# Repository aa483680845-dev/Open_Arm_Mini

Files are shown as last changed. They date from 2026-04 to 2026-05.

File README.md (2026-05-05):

# Open Arm Mini

基于 ROS2 的开源六自由度机械臂，通过 FDCAN 总线驱动达秒（Damiao）系列电机，采用 MIT 阻抗控制模式，支持真实硬件控制与 Mujoco 仿真，具备手柄末端控制和重力补偿功能。

另一个开源项目：moveit2轨迹规划:https://github.com/aa483680845-dev/Arm_Moveit2.git

运行环境：Ubuntu 24.04 LTS + ROS2 Jazzy

## 演示

**手柄控制**

https://github.com/user-attachments/assets/3d2e06fe-9ed9-414d-ab63-fa3fa3a4508c

**重力补偿**

https://github.com/user-attachments/assets/b24e1ee6-b301-45b6-a565-f904d05fffcf

## 目录结构

```
Open_Arm_Mini/
├── image/                  # 演示视频
├── SW_model/               # SolidWorks 机械臂三维模型
│   └── First_edition/
│       ├── SLDPRT/         # SolidWorks 原始零件文件
│       └── STEP/           # 通用 STEP 格式，可导入其他 CAD 软件
└── ros2_package/           # ROS2 控制软件包
    ├── robot_description/  # URDF/xacro 描述文件及 STL 网格模型
    ├── robot_dm_driver/    # 达秒电机底层驱动（FDCAN/MIT 协议）
    ├── my_robot_hardware/  # ROS2 硬件接口层
    ├── robot_controllers/  # 电机控制器（手柄控制 / 重力补偿）
    ├── robot_pinocchio/    # Pinocchio 逆运动学节点
    ├── robot_bringup/      # Launch 启动文件及控制器配置
    └── README.md           # 软件包详细文档
```

## 软件包文档

ROS2 软件包的详细说明（环境配置、编译运行、架构设计、各包接口）请参阅

👉 [ros2_package/README.md](ros2_package/README.md)

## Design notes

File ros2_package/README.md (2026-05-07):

## 项目概述

本项目是基于 ROS2 的**六自由度机械臂控制系统**，通过 FDCAN 总线驱动达秒（Damiao）系列电机，采用 MIT 阻抗控制模式，支持真实硬件控制、Mujoco 仿真，控制方面可以采用手柄控制末端关节，拥有重力补偿功能。

## 环境配置

运行在 Ubuntu 24.04 LTS 系统上，ROS2 Jazzy 版本。

### 依赖安装

```bash
sudo apt install ros-jazzy-ros2-control ros-jazzy-ros2-controllers
sudo apt install ros-jazzy-joy
sudo apt install ros-jazzy-pinocchio
sudo apt install libusb-1.0-0-dev
```

### 可视化工具（可选）

```bash
sudo apt install ros-jazzy-plotjuggler
```

## 编译与运行

```bash
cd ~/Project/ros2_package
colcon build --symlink-install
source install/setup.bash
```

### 控制方案切换

配置文件：`robot_description/urdf/robot_1.ros2_control.xacro` 的 `<plugin>` 部分：

| 插件 | 用途 |
|---|---|
| `mock_components/GenericSystem` | 模拟组件，用于代码调试（当前默认） |
| `mobile_base_hardware/MobileBaseHardwareInterface` | 真实硬件，需接 USB2CAN 连接电机 |
| `mujoco_ros2_control/MujocoSystemInterface` | Mujoco 仿真 |

### 启动命令

```bash
# 运行控制节点（真实/模拟硬件）
ros2 launch robot_bringup robot_controllers.launch.py

# 运行 Mujoco 仿真节点
ros2 launch robot_bringup robot_mujoco.launch.py

# 运行手柄 + Pinocchio 逆运动学控制
ros2 launch robot_bringup my_robot_pin.launch.py
```

## 软件包架构

```
手柄输入 → PinocchioInverseNode → arm_MIT_command_controller/commands
                                              ↓
                               MotorController（position_ff / gravity_comp）
                                              ↓
                               MobileBaseHardwareInterface（250 Hz 循环）
                                              ↓  
                               robot_dm_driver（CAN 协议，CANFD）
                                              ↓
                               达秒电机（MIT 阻抗：kp·Δq + kd·Δdq + τ_ff）
```

### 各软件包简要说明（多数软件包内部都写了README.md文档）

| 软件包 | 功能 |
|---|---|
| `robot_description` | 包含 URDF、xacro、xml机械臂描述文件，STL网格模型，主要需要修改的是robot_1.ros2_control.xacro，可以修改MIT增益参数、控制模式|
| `robot_dm_driver` | 包含[达秒官方的封装闭源库](https://gitee.com/kit-miao/dm-tools/tree/master/DM_DeviceSDK/C&C++) `libdm_device.so`，pub_user.h API 接口, src里面写的是对API的实现包含MIT控制模式的实现，接收电机反馈数据。|
| `my_robot_hardware` | 介于控制器和底层API之间，实现了 ROS2 硬件接口，起到的主要作用是设置电机ID、发送控制器的指令、接收电机反馈数据传送给控制器(如：关节广播控制器) |
| `robot_controllers` | 含有两种控制模式，一个是手柄控制，接收上层节点的关节速度指令，积分为位置，另一种是接收位置指令，通过pinocchio的函数实现重力补偿，此外控制器还包含了低通滤波。控制器控制模式可以通过配置文件修改：`robot_bringup/config/ros2_controllers.yaml` |
| `robot_pinocchio` | DLS 逆运动学节点，手柄轴输入 → 关节速度指令，250 Hz 定时发布 |
| `robot_bringup` | Launch 启动文件及控制器 YAML 配置文件，和一个rviz保存的配置文件 |

### 电机驱动（`robot_dm_driver`）
- 只要是达秒拥有MIT控制的电机应该是都可以用的，本项目仅使用了 DM_4340 和 DM_4310 系列
- 关于MIT控制详细内容请参考[达秒官方文档](https://gl1po2nscb.feishu.cn/wiki/Y3OEwMr4GivZU9kZqkjctmGinye)
- CANFD 双波特率：标称 1 Mbps，数据段 5 Mbps
- `libdm_device.so` 为[达秒官方的闭源二进制库](https://gitee.com/kit-miao/dm-tools/tree/master/DM_DeviceSDK/C&C++)，位于 `robot_dm_driver/lib/`，运行时必须存在
- 电机状态由互斥锁保护，读取时使用 `dm_motor_snapshot(idx, &q, &dq, &tau)` 保证线程安全

### 硬件接口（`my_robot_hardware`）
- 类名：`MobileBaseHardwareInterface`（命名有误导性，实为机械臂接口）
- 插件描述文件：`my_robot_hardware_interface.xml`
- **`on_init()`**：从 URDF `<param>` 读取每关节 kp/kd，创建 damiao handle，查找 USB2CAN 设备
- **`on_configure()`**：打开设备，打印固件版本和序列号
- **`on_activate()`**：初始化 CANFD 通道，注册 6 个电机（CAN ID 0x01–0x06），开启通道，使能控制，等待最多 500 ms 接收首次反馈
- **`read()`**：突变滤波（偏差 > 0.2 rad 则保持上帧值）+ 低通滤波（alpha=0.4）
- **`write()`**：调用 `dm_control_mit()` 透传 pos/vel/eff，含 NaN 保护（跳过异常帧）

### 电机控制器（`robot_controllers`）
- 命名空间：`robot_controller::MotorController`（注意：非 `robot_controllers`）
- 插件：`robot_controller::MotorController`
- **`position_ff` 模式**（默认）：读取速度指令（`data[i*3+1]`），低通滤波（alpha=0.4），积分出位置目标，dt 限幅 [0.5 ms, 10 ms]
- **`gravity_comp` 模式**：使用 Pinocchio `computeGeneralizedGravity()` 计算重力力矩，pos=当前位置，vel=0，eff=τ_gravity
- 订阅话题：`arm_MIT_command_controller/commands`（`Float64MultiArray`，18 元素，每关节 `[pos, vel, eff]`）

### Pinocchio 逆运动学（`robot_pinocchio`）
- 节点名：`pinocchio_inverse_node`
- 使用阻尼最小二乘法（DLS）雅可比伪逆，`IK_DT=0.04`，奇异点阈值 `IK_EPS=0.01`
- 定时器周期 4 ms（约 250 Hz）发布关节速度指令
- 手柄左摇杆（LEFTX/LEFTY）→ 末端笛卡尔速度 → DLS 映射为 6 个关节速度,本项目没有添加末端姿态控制，如果需要你可以尝试添加；
- 速度缩放因子 `factor=0.03`，奇异度指标 `ratio`（< 1 表示接近奇异）
- 订阅 `joint_states`关节状态，发布到 `arm_MIT_command_controller/commands`控制器
- URDF 路径通过 `ament_index_cpp::get_package_share_directory("robot_description")` 动态获取

### 控制器配置
- 更新频率：250 Hz（在 `robot_bringup/config/ros2_controllers.yaml` 中设置）
- 各关节 kp/kd 增益定义在 `robot_description/urdf/robot_1.ros2_control.xacro`
- **注意**：`ros2_controllers.yaml` 中 URDF 路径为绝对路径，工作空间移动后需同步修改

## 未来更新
-本项目代码还有许多问题，之后会积极改进。
-关于机械臂新的功能的更新，本人会更侧重于 moveit2 这个项目:https://github.com/aa483680845-dev/Arm_Moveit2.git

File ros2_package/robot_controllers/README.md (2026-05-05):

# robot_controllers

## 概述

本包实现了一个自定义 ROS2 控制器 `MotorController`，用于驱动六自由度机械臂的达秒（Damiao）系列电机，支持**位置前馈（position_ff）**和**重力补偿（gravity_comp）**两种控制模式。

##个人吐槽

写自定义控制器其实不是必要的，如果想要分别实现手柄控制和重力补偿，可以使用官方提供的forward_command_controller和force_torque_sensor_broadcaster控制器，使用launch选择性的加载控制器。
如果想要实现在重力补偿的基础上实现遥控制，可以将重力补偿部分写入hardware_interface。至于为什么自写控制器，主要是当时我刚开始学习ros2_control，觉得自己要实现的功能官方提供的控制器无法满足。
其次，自写控制器不用担心上点跳变到零点问题，还可以自己在控制器中加入一些滤波逻辑，集成度更高（doge），还有控制器的逻辑和硬件组件的逻辑差不多，所以并不难写。

## 控制模式

通过配置文件中的 `control_mode` 参数切换，配置文件路径：`robot_bringup/config/ros2_controllers.yaml`。

### `position_ff`（默认）

接收上游发布的关节**速度指令**，经低通滤波后积分为位置目标，同时将滤波后的速度作为前馈量发送给硬件。

```
速度指令 (vel_cmd)
    → 低通滤波（alpha = 0.4）
    → 积分（dt 限幅 [0.5ms, 10ms]）
    → 位置目标 (pos_cmd)
    → 硬件接口 [pos_cmd, vel_filtered, 0.0]
```

### `gravity_comp`

读取当前关节角，利用 Pinocchio `computeGeneralizedGravity()` 实时计算各关节重力补偿力矩，并将当前位置作为目标位置发送，使机械臂保持当前姿态的同时补偿重力。

```
当前关节角 q (来自 state_interfaces)
    → Pinocchio RNEA → τ_gravity = g(q)
    → 硬件接口 [q_now, 0.0, τ_gravity]
```

> 发送 `pos = q_now`，使 MIT 控制器中的 `kp*(q_now - q_actual) ≈ 0`，位置增益几乎不出力；
> 发送 `vel = 0`，MIT 控制器中的 `-kd * dq_actual` 提供速度阻尼。

---

## 接口说明

### 订阅话题

| 话题 | 消息类型 | 说明 |
|---|---|---|
| `arm_MIT_command_controller/commands` | `std_msgs/Float64MultiArray` | 上游指令，18 元素，每关节 `[pos, vel, eff]` 排列（`position_ff` 模式仅使用 `vel`，即 `data[i*3+1]`） |

### 命令接口（写入硬件）

每个关节输出三路命令接口：`position`、`velocity`、`effort`。

### 状态接口（读取硬件）

每个关节读取三路状态接口：`position`、`velocity`、`effort`。

---

## 参数

| 参数 | 类型 | 默认值 | 说明 |
|---|---|---|---|
| `joints` | `string[]` | `[]` | 受控关节名称列表，不能为空 |
| `control_mode` | `string` | `"position_ff"` | 控制模式：`position_ff` 或 `gravity_comp` |
| `urdf_path` | `string` | `""` | URDF 文件路径，仅 `gravity_comp` 模式需要 |

---

## 插件信息

- **命名空间**：`robot_controller`
- **类名**：`robot_controller::MotorController`
- **插件描述文件**：`motor_controller_plugin.xml`
- **基类**：`controller_interface::ControllerInterface`

---
## 参考资料

- [ROS2 Controllers 官方文档 - 编写自定义控制器](https://control.ros.org/jazzy/doc/ros2_controllers/doc/writing_new_controller.html)
- [ros2_controllers 源码](https://github.com/ros-controls/ros2_controllers)
- [达秒电机 MIT 控制模式文档](https://gl1po2nscb.feishu.cn/wiki/Y3OEwMr4GivZU9kZqkjctmGinye)
- [ros2插件编写](https://docs.ros.org/en/jazzy/Tutorials/Beginner-Client-Libraries/Pluginlib.html#creating-and-using-plugins-c)

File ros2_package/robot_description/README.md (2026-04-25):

# robot_description

## 概述

本包包含六自由度机械臂的所有模型描述文件，包括 URDF、xacro 配-置、STL 网格模型，以及 Mujoco 仿真所需的 XML 文件。

---

## 包结构

```
robot_description/
├── urdf/
│   ├── robot_1.urdf                    # 主 URDF 文件（由 SW 插件导出）
│   ├── my_robot.xacro                  # xacro 入口文件
│   ├── robot_1.ros2_control.xacro      # ros2_control 硬件接口配置（含 MIT 增益）
│   └── Mujoco_xml/
│       ├── robot_mujoco.xml            # Mujoco 机器人模型
│       └── scene.xml                   # Mujoco 场景（地面、光照）
├── meshes/                             # 各连杆 STL 网格模型
│   ├── base_link.STL
│   ├── link_1.STL ~ link_6.STL
├── config/
│   └── default.rviz                    # RViz 默认配置
└── launch/
    └── robot_1_rviz.launch.py          # 启动 RViz 可视化
```

---

## 硬件接口配置（`robot_1.ros2_control.xacro`）

这是最常需要修改的文件，用于切换控制插件和调整 MIT 增益参数。

### 插件切换

修改 `<plugin>` 标签选择运行模式：

| 插件 | 用途 | 备注 |
|---|---|---|
| `mock_components/GenericSystem` | 模拟组件 | 默认，用于代码调试，无需硬件 |
| `mobile_base_hardware/MobileBaseHardwareInterface` | 真实硬件 | 需接 USB2CAN 连接电机 |
| `mujoco_ros2_control/MujocoSystemInterface` | Mujoco 仿真 | 需配合 `robot_mujoco.xml` 使用 |

```xml
<hardware>
    <!-- 三选一，取消对应行的注释 -->
    <plugin>mock_components/GenericSystem</plugin>
    <!-- <plugin>mobile_base_hardware/MobileBaseHardwareInterface</plugin> -->
    <!-- <plugin>mujoco_ros2_control/MujocoSystemInterface</plugin>
    <param name="mujoco_model">$(find robot_description)/urdf/Mujoco_xml/robot_mujoco.xml</param> -->
</hardware>
```

### MIT 增益参数

各关节的 `kp`（位置增益）和 `kd`（速度增益）透传给达秒电机 MIT 阻抗控制器：

| 关节 | kp | kd | 对应电机 |
|---|----|----|---|
| joint_1 | 80.0 | 10.0 | DM_4340 |
| joint_2 | 90.0 | 15.0 | DM_4340 |
| joint_3 | 120.0 | 20.0 | DM_4340 |
| joint_4 | 20.0 | 1.0 | DM_4310 |
| joint_5 | 20.0 | 1.0 | DM_4310 |
| joint_6 | 20.0 | 1.0 | DM_4310 |

> MIT 阻抗控制输出：`τ = kp*(q_cmd - q) + kd*(dq_cmd - dq) + τ_ff`
> 调整增益时请参考[达秒电机官方文档](https://gl1po2nscb.feishu.cn/wiki/Y3OEwMr4GivZU9kZqkjctmGinye)中各电机型号的参数上限。

---

## URDF 模型来源

机器人 URDF 由 **SolidWorks** 三维模型通过开源插件 [sw_urdf_exporter](https://wiki.ros.org/action/fullsearch/sw_urdf_exporter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) 导出，网格模型同步导出为 STL 格式。

详细操作教程可参考：[B站视频教程](https://www.bilibili.com/video/BV16izyYeEDm/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)

---

## Mujoco 仿真

如果想要使用这个Mujoco仿真，一定要看下面这个开源项目，里面有详细的教程。
仿真基于开源项目 [mujoco_ros2_control](https://github.com/moveit/mujoco_ros2_control) 实现，包含两个 XML 文件：

- **`robot_mujoco.xml`**：机器人本体模型，包含连杆、关节、执行器定义
- **`scene.xml`**：仿真场景，包含地面平面和光照配置

启动仿真：

```bash
ros2 launch robot_bringup robot_mujoco.launch.py
```

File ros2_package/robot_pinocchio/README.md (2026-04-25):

# robot_pinocchio

基于 Pinocchio 的六自由度机械臂逆运动学节点，将手柄摇杆输入转换为关节速度指令，以 250 Hz 频率发布给控制器。

## 功能概述

- 从 URDF 加载机器人模型，使用 Pinocchio 计算运动学
- 读取手柄摇杆输入，映射为末端执行器的笛卡尔速度
- 采用阻尼最小二乘法（DLS）求解雅可比伪逆，将笛卡尔速度转换为关节速度
- 通过方向键（D-pad）实时调节速度缩放因子
- 在收到第一帧关节状态前不发布任何指令，避免零位跳变

## 文件结构

```
robot_pinocchio/
├── include/robot_pinocchio/
│   └── pinocchio_inverse.hpp     # IK 求解器类声明，手柄/关节数据结构
├── src/
│   ├── pinocchio_inverse.cpp     # DLS 逆运动学实现
│   └── pinocchio_main.cpp        # ROS2 节点：订阅、发布、定时器
├── CMakeLists.txt
└── package.xml
```

## 话题

| 方向 | 话题名 | 消息类型 | 说明 |
|---|---|---|---|
| 订阅 | `joint_states` | `sensor_msgs/JointState` | 读取当前各关节位置 |
| 订阅 | `joy` | `sensor_msgs/Joy` | 读取手柄摇杆和按键输入 |
| 发布 | `arm_MIT_command_controller/commands` | `std_msgs/Float64MultiArray` | 发布 18 元素关节指令（每关节 `[pos, vel, eff]`） |

发布的指令中：`pos=0`，`vel=关节速度`，`eff=0`，由下游 `MotorController` 在 `position_ff` 模式下积分位置目标。

## 手柄映射

| 手柄输入 | 轴索引 | 作用 |
|---|---|---|
| 左摇杆 Y 轴（前后） | LEFTY (1) | 末端 X 方向平移速度 |
| 左摇杆 X 轴（左右） | LEFTX (0) | 末端 Y 方向平移速度 |
| 右摇杆 Y 轴（前后） | RIGHTY (4) | 末端 Z 方向平移速度 |
| D-pad 上 | DPAD_Y > 0.5 | 速度缩放因子 +0.01 |
| D-pad 下 | DPAD_Y < -0.5 | 速度缩放因子 -0.01 |

> 当前版本仅控制末端平移，姿态速度分量固定为零。如需添加姿态控制，可将右摇杆 X 轴或扳机等映射到 `v_world(3~5)`。

## 关键参数

| 参数 | 位置 | 默认值 | 说明 |
|---|---|---|---|
| `IK_DT` | `pinocchio_inverse.hpp` | `0.04` | IK 积分步长（s） |
| `IK_EPS` | `pinocchio_inverse.hpp` | `0.01` | 奇异点判断阈值 |
| `factor` | `pinocchio_inverse.hpp` | `0.03` | 速度缩放因子，范围 [0.01, 0.05] |
| `damp` | `pinocchio_inverse.cpp` | `1e-4` | DLS 阻尼系数，防止奇异点下速度爆炸 |
| 定时器周期 | `pinocchio_main.cpp` | `4 ms` | 控制频率约 250 Hz |

## 算法说明

### DLS 逆运动学

核心思路：给定末端期望笛卡尔速度 $\mathbf{v}$，求满足 $J\dot{q} = \mathbf{v}$ 的关节速度 $\dot{q}$。

直接求逆在奇异点附近数值不稳定，因此采用**阻尼最小二乘法**（Damped Least Squares）：

$$\dot{q} = J^T (J J^T + \lambda^2 I)^{-1} \mathbf{v}$$

其中 $\lambda^2 = 10^{-4}$ 为阻尼系数。

实现步骤（`ik_solve`）：

1. 以当前关节角 `q` 做正运动学，更新末端位姿
2. 将世界坐标系下的笛卡尔速度转换到末端局部坐标系（`oMi.actInv`）
3. 用 `pinocchio::computeJointJacobian` 计算关节 6 的几何雅可比 $J \in \mathbb{R}^{6\times6}$
4. 组装 $JJ^T + \lambda I$ 并用 LDLT 分解求解线性方程组
5. 输出关节速度 $\dot{q}$，存入 `v_`

### 多线程设计

节点使用 `MultiThreadedExecutor`，三个回调各属独立的 `MutuallyExclusive` 回调组：

- **`joint_state` 回调**：更新关节角缓冲，设置 `joint_state_received_` 标志
- **`joy` 回调**：更新手柄数据缓冲
- **定时器回调**：无锁快照两个缓冲 → 调用 IK 求解 → 发布指令

两个缓冲各有独立互斥锁，定时器取快照时加锁时间极短，避免长时间阻塞。

## 与其他节点的数据流

```
sensor_msgs/Joy (手柄驱动)
        │  /joy
        ▼
PinocchioInverseNode
        │  订阅 joint_states（关节反馈）
        │  DLS IK 求解（250 Hz）
        │  /arm_MIT_command_controller/commands
        ▼
MotorController（position_ff 模式）
        │  积分位置目标 + 低通滤波
        ▼
MobileBaseHardwareInterface → 达秒电机（MIT 阻抗控制）
```

## 启动

```bash
# 同时启动控制器和 Pinocchio IK 节点
ros2 launch robot_bringup my_robot_pin.launch.py
```

需要确保：
- 手柄已连接并由 `ros-jazzy-joy` 的 `joy_node` 发布 `/joy` 话题
- `robot_description` 包下存在编译好的 `robot_1.urdf`（由 xacro 生成）
- 控制器已加载并处于 `position_ff` 模式（见 `robot_bringup/config/ros2_controllers.yaml`）

## 依赖

```bash
sudo apt install ros-jazzy-pinocchio
sudo apt install ros-jazzy-joy
```

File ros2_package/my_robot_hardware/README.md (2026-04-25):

-硬件组件，其功能主要是对robot_dm_driver的实例化，接收ros2_controller接口命令

关于插件命名为 mobile_base_hardware/MobileBaseHardwareInterface 具有误导性，其实是机械臂的硬件组件，但是这个代码是从学习ros2_control过程中一步步改出来的，所以这个名字我就懒得改了.......

-[硬件组件介绍](https://control.ros.org/jazzy/doc/getting_started/getting_started.html#hardware-components)

-这个项目是使用的jazzy版本的ros2_control,关于humbel与jazzy的区别，如果需要迁移到humble版本，可以参考[这里](https://control.ros.org/jazzy/doc/ros2_control/doc/migration.html), 如果不需要，可以忽略这个部分。
对于本项目最大的改变(这里指的是从humbel迁移到jazzy)应该就是[命令/状态接口的迁移](https://control.ros.org/jazzy/doc/ros2_control/doc/migration.html#migration-of-command-stateinterfaces)

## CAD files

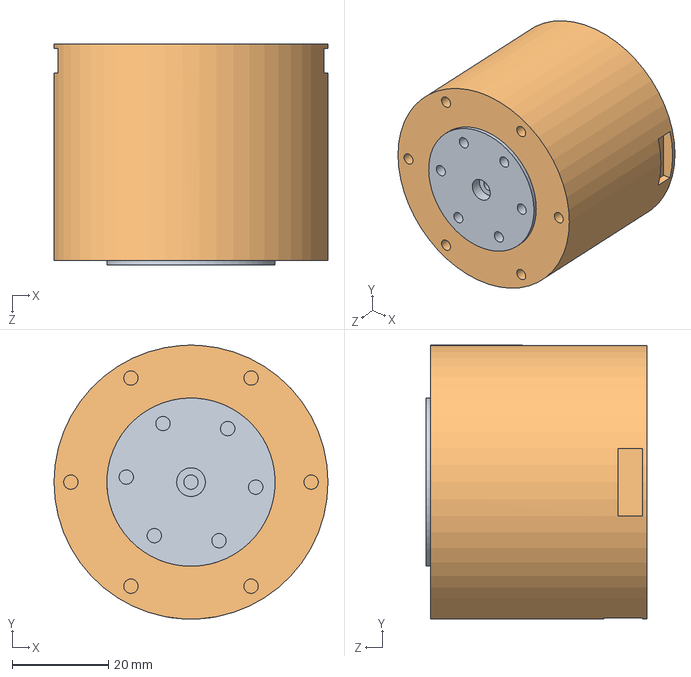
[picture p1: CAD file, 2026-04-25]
SW_model/First_edition/SLDPRT/DM4310/DM4310.SLDASM
57.0 x 56.9 x 46.0 mm
DM4310定子
DM4310转子

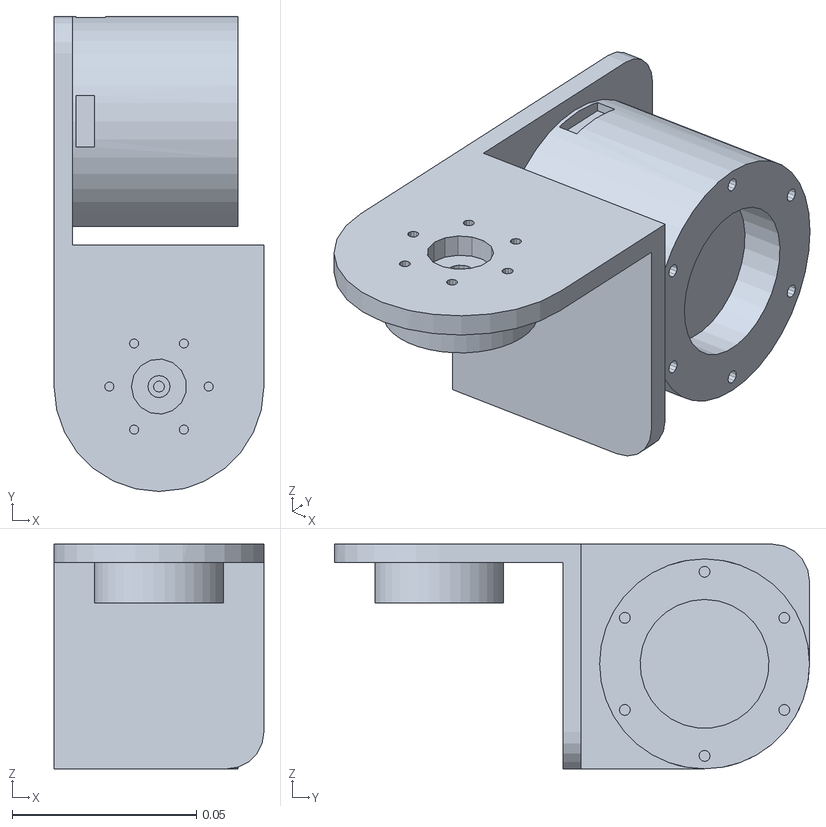
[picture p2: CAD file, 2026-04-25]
ros2_package/robot_description/meshes/link_3.STL
0.057 x 0.129 x 0.061

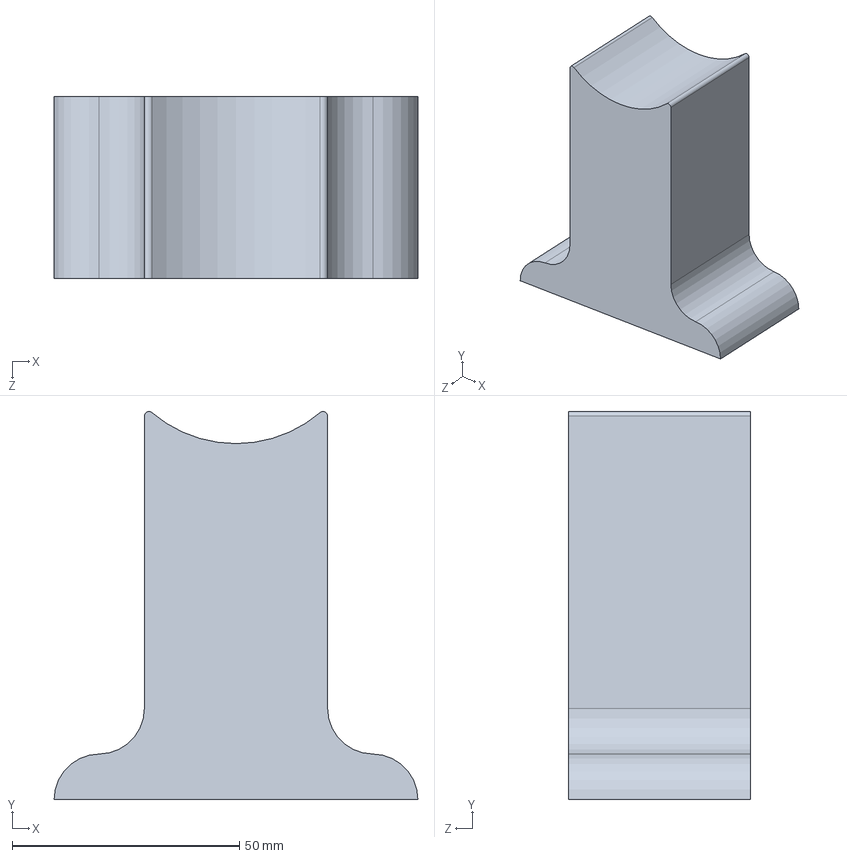
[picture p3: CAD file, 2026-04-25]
SW_model/First_edition/SLDPRT/3轴垫块.SLDPRT
80.0 x 85.3 x 40.0 mm

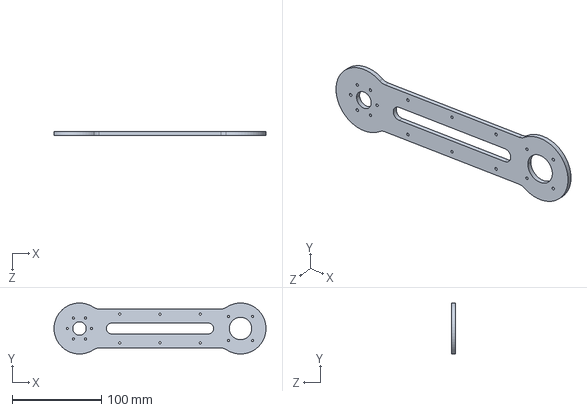
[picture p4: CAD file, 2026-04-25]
SW_model/First_edition/STEP/23连杆.STEP
236.9 x 57.0 x 4.00 mm

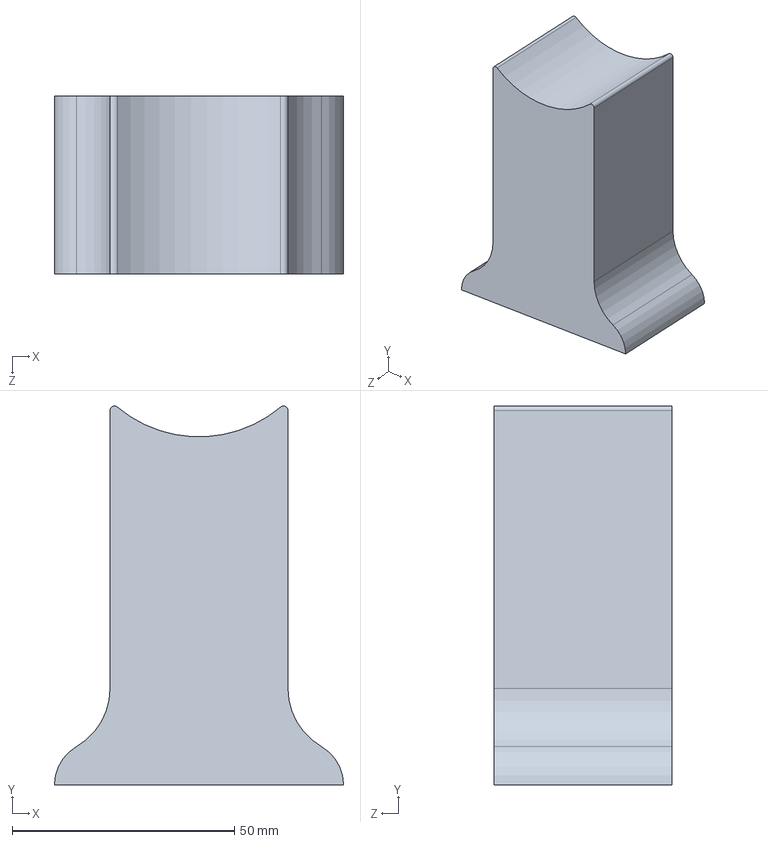
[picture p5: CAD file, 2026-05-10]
SW_model/Second_edition/3轴垫块.SLDPRT
65.0 x 85.2 x 40.0 mm

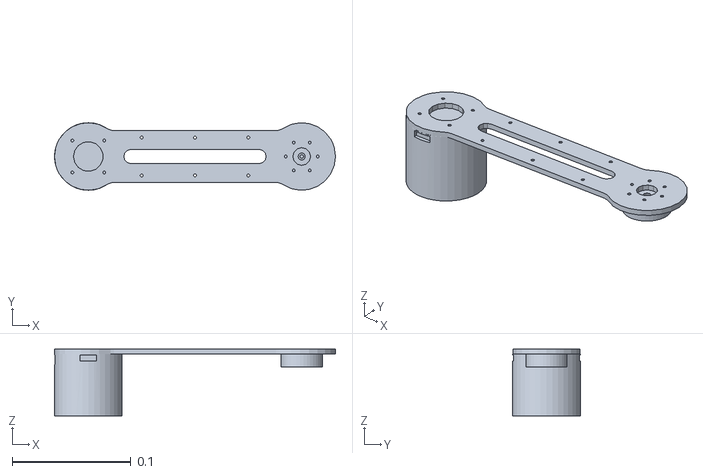
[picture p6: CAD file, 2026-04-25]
ros2_package/robot_description/meshes/link_2.STL
0.237 x 0.057 x 0.0563

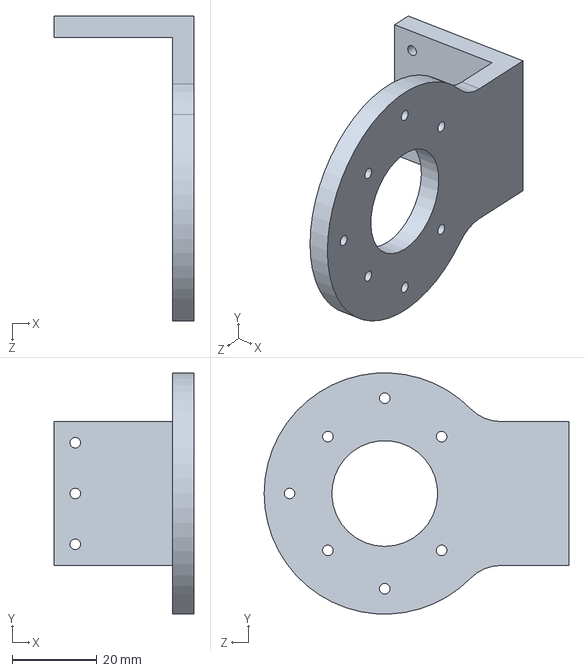
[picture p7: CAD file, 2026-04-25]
SW_model/First_edition/SLDPRT/45轴连接件.SLDPRT
33.0 x 56.9 x 72.0 mm

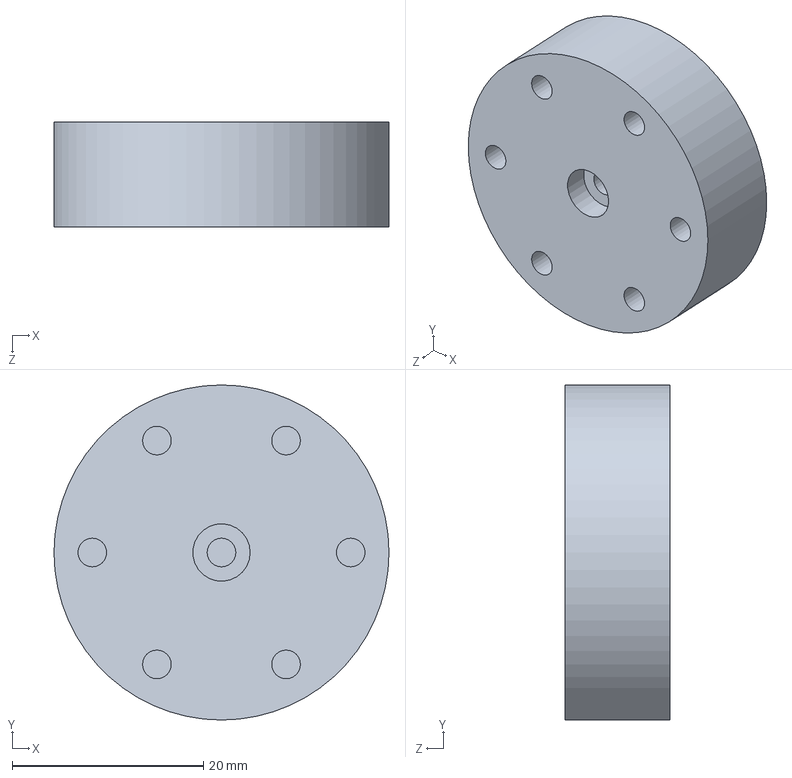
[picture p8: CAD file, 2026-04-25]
SW_model/First_edition/SLDPRT/DM4310/DM4310转子.SLDPRT
35.0 x 35.0 x 11.0 mm

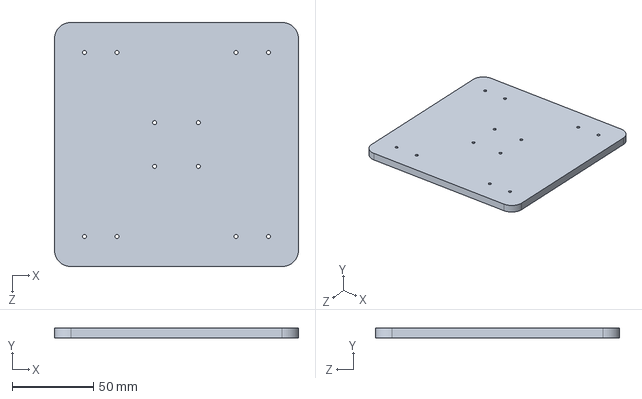
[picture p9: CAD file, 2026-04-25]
SW_model/First_edition/STEP/底座.STEP
150.0 x 6.00 x 150.0 mm

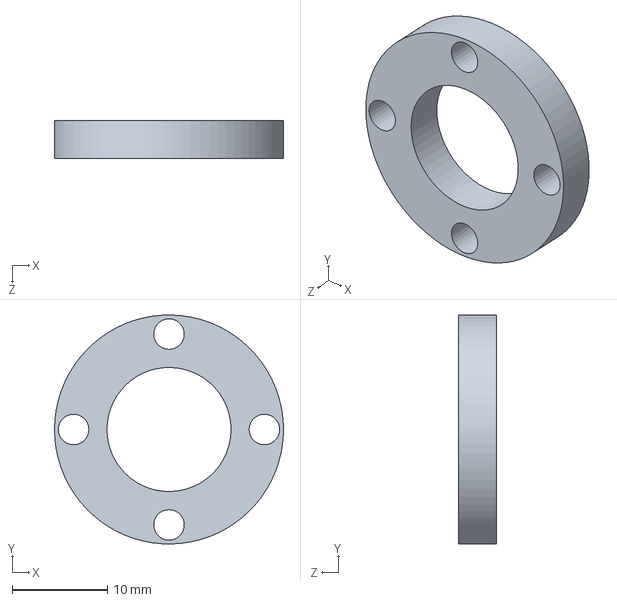
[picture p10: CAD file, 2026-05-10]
SW_model/Second_edition/轴承压块.SLDPRT
24.0 x 24.0 x 4.00 mm

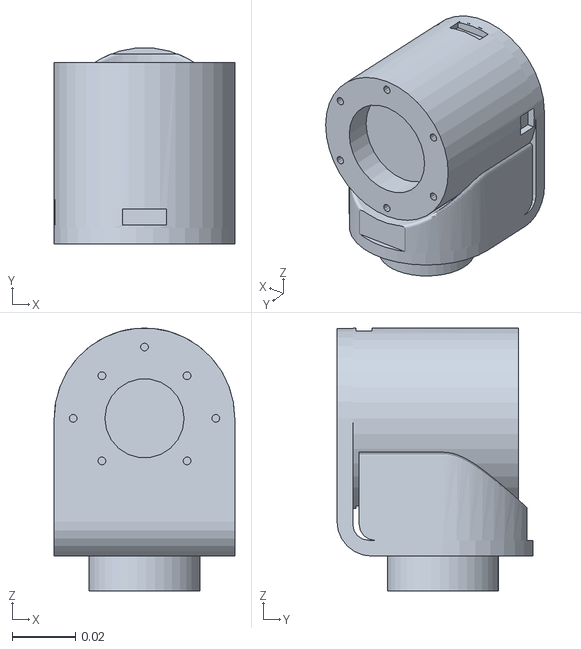
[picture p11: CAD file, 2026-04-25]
ros2_package/robot_description/meshes/link_1.STL
0.057 x 0.0619 x 0.083

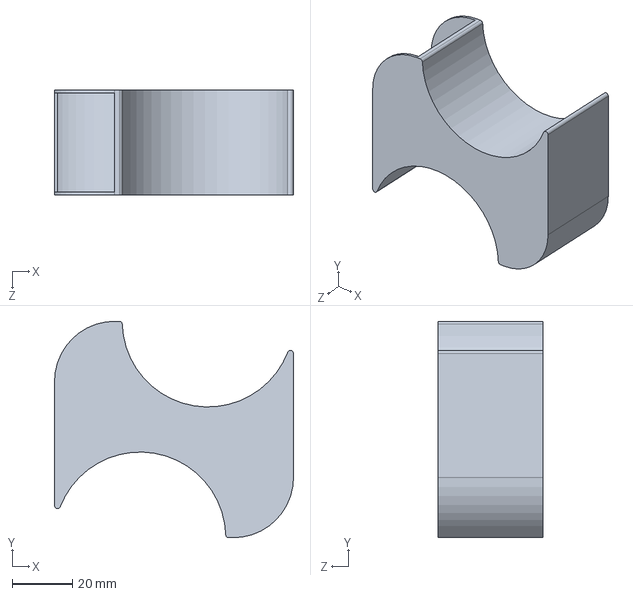
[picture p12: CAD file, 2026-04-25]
SW_model/First_edition/SLDPRT/15轴垫块.SLDPRT
79.5 x 72.0 x 35.0 mm

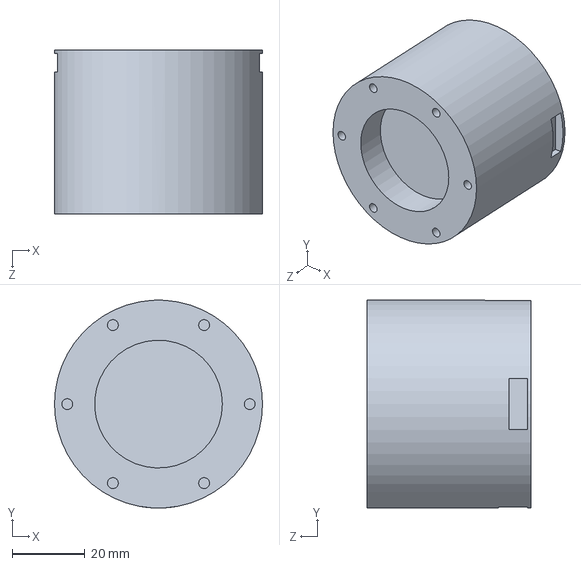
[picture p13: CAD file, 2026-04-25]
SW_model/First_edition/SLDPRT/DM4310/DM4310定子.SLDPRT
57.0 x 56.9 x 45.0 mm

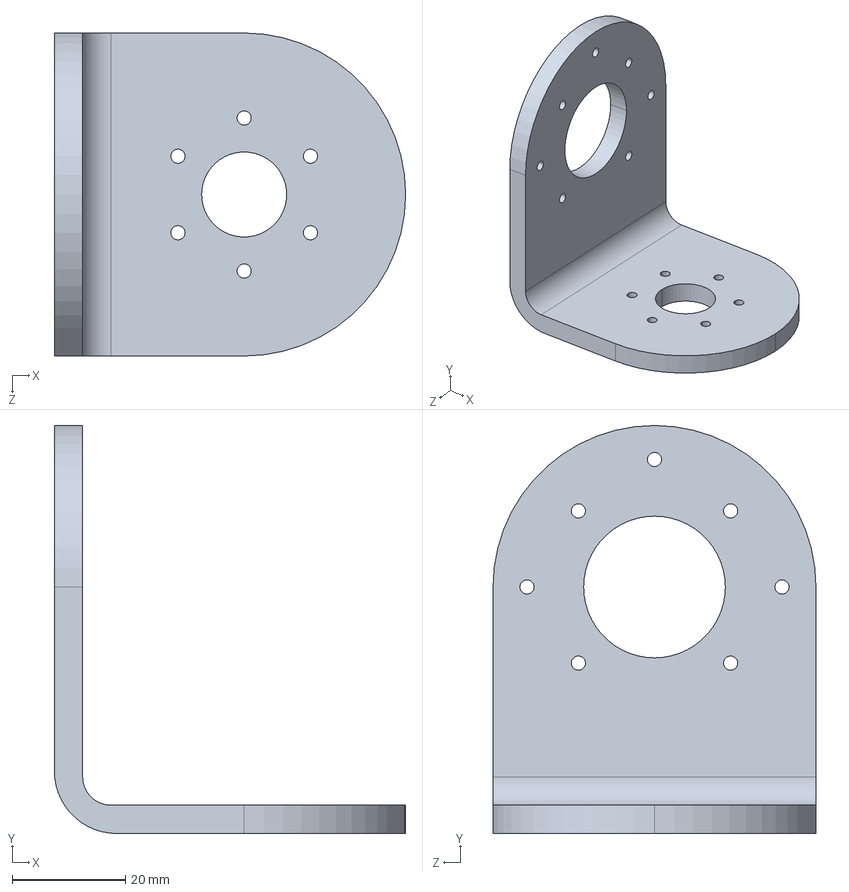
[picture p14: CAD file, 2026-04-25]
SW_model/First_edition/STEP/12轴连接件.STEP
62.0 x 72.0 x 57.0 mm

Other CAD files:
SW_model/Second_edition/DM4340.SLDASM
SW_model/First_edition/SLDPRT/robot_1.SLDASM
SW_model/Second_edition/robot_1.SLDASM
ros2_package/robot_description/meshes/link_6.STL
SW_model/First_edition/SLDPRT/34轴连接件.SLDPRT
SW_model/First_edition/SLDPRT/56轴连接件.SLDPRT
SW_model/First_edition/SLDPRT/底座.SLDPRT
SW_model/First_edition/STEP/34轴连接件.STEP
SW_model/First_edition/STEP/34轴连杆.STEP
SW_model/First_edition/STEP/56轴连接件.STEP
SW_model/First_edition/STEP/大底座.STEP
SW_model/Second_edition/12轴垫片.SLDPRT
SW_model/Second_edition/12轴连接件.SLDPRT
SW_model/Second_edition/23连杆.SLDPRT
SW_model/Second_edition/34轴连杆_改进版_2.SLDPRT
SW_model/Second_edition/4 25铜柱.SLDPRT
SW_model/Second_edition/6 6 40 M3.SLDPRT
SW_model/Second_edition/DM4340定子.SLDPRT
SW_model/Second_edition/DM4340转子.SLDPRT
SW_model/Second_edition/P R连接件.SLDPRT
SW_model/Second_edition/P R连接件2.SLDPRT
SW_model/Second_edition/P电机固定.SLDPRT
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

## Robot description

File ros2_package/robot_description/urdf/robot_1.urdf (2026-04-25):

<?xml version="1.0" encoding="utf-8"?>
<!-- This URDF was automatically created by SolidWorks to URDF Exporter! Originally created by Stephen Brawner (brawner@gmail.com) 
     Commit Version: 1.6.0-4-g7f85cfe  Build Version: 1.6.7995.38578
     For more information, please see http://wiki.ros.org/sw_urdf_exporter -->
<robot name="robot_1">
  <link name="base_link">
    <inertial>
      <origin xyz="-4.70844142286264E-08 1.29418732298242E-06 0.0057678" rpy="0 0 0" />
      <mass value="4.06800157701675" />
      <inertia ixx="0.0235898554568089" ixy="-9.64268018638175E-11" ixz="6.33404608418726E-12" iyy="0.023592876806635" iyz="9.80269028872486E-08" izz="0.0471182504343923" />
    </inertial>
    <visual>
      <origin xyz="0 0 0" rpy="0 0 0" />
      <geometry>
        <mesh filename="package://robot_description/meshes/base_link.STL" />
      </geometry>
      <material name="">
        <color rgba="0.647058823529412 0.619607843137255 0.588235294117647 1" />
      </material>
    </visual>
    <collision>
      <origin xyz="0 0 0" rpy="0 0 0" />
      <geometry>
        <mesh filename="package://robot_description/meshes/base_link.STL" />
      </geometry>
    </collision>
  </link>
  <link name="link_1">
    <inertial>
      <origin xyz="-0.0001798 -0.0062513 -0.0147465" rpy="0 0 0" />
      <mass value="0.6895799" />
      <inertia ixx="0.0005223" ixy="0.0000002" ixz="-0.0000002" iyy="0.0004968" iyz="0.0000271" izz="0.0003605" />
    </inertial>
    <visual>
      <origin xyz="0 0 0" rpy="0 0 0" />
      <geometry>
        <mesh filename="package://robot_description/meshes/link_1.STL" />
      </geometry>
      <material name="">
        <color rgba="0.827450980392157 0.827450980392157 0.819607843137255 1" />
      </material>
    </visual>
    <collision>
      <origin xyz="0 0 0" rpy="0 0 0" />
      <geometry>
        <mesh filename="package://robot_description/meshes/link_1.STL" />
      </geometry>
    </collision>
  </link>
  <joint name="joint_1" type="revolute">
    <origin xyz="0.00019927 -0.001877 0.10675" rpy="0 0 0" />
    <parent link="base_link" />
    <child link="link_1" />
    <axis xyz="0 0 1" />
    <limit lower="-3" upper="3" effort="27" velocity="3" />
  </joint>
  <link name="link_2">
    <inertial>
      <origin xyz="-0.1309040 0.0000000 0.0144901" rpy="0 0 0" />
      <mass value="0.6370289" />
      <inertia ixx="0.0003093" ixy="0.0000000" ixz="-0.0004001" iyy="0.0034922" iyz="0.0000000" izz="0.0034502" />
    </inertial>
    <visual>
      <origin xyz="0 0 0" rpy="0 0 0" />
      <geometry>
        <mesh filename="package://robot_description/meshes/link_2.STL" />
      </geometry>
      <material name="">
        <color rgba="0.827450980392157 0.827450980392157 0.819607843137255 1" />
      </material>
    </visual>
    <collision>
      <origin xyz="0 0 0" rpy="0 0 0" />
      <geometry>
        <mesh filename="package://robot_description/meshes/link_2.STL" />
      </geometry>
    </collision>
  </link>
  <joint name="joint_2" type="revolute">
    <origin xyz="0 0 0" rpy="-1.5708 0 0" />
    <parent link="link_1" />
    <child link="link_2" />
    <axis xyz="0 0 1" />
    <limit lower="-3" upper="3" effort="27" velocity="3" />
  </joint>
  <link name="link_3">
    <inertial>
      <origin xyz="-0.0058307 0.0495532 0.0062562" rpy="0 0 0" />
      <mass value="0.7024189" />
      <inertia ixx="0.0008960" ixy="0.0000733" ixz="-0.0000176" iyy="0.0004118" iyz="0.0001846" izz="0.0008387" />
    </inertial>
    <visual>
      <origin xyz="0 0 0" rpy="0 0 0" />
      <geometry>
        <mesh filename="package://robot_description/meshes/link_3.STL" />
      </geometry>
      <material name="">
        <color rgba="0.827450980392157 0.827450980392157 0.819607843137255 1" />
      </material>
    </visual>
    <collision>
      <origin xyz="0 0 0" rpy="0 0 0" />
      <geometry>
        <mesh filename="package://robot_description/meshes/link_3.STL" />
      </geometry>
    </collision>
  </link>
  <joint name="joint_3" type="revolute">
    <origin xyz="-0.18 0 0" rpy="-3.1416 0 0" />
    <parent link="link_2" />
    <child link="link_3" />
    <axis xyz="0 0 1" />
    <limit lower="-3" upper="3" effort="27" velocity="3" />
  </joint>
  <link name="link_4">
    <inertial>
      <origin xyz="0.0002323 0.0070423 0.1600094" rpy="0 0 0" />
      <mass value="0.5211502" />
      <inertia ixx="0.0026660" ixy="0.0000000" ixz="0.0000000" iyy="0.0026491" iyz="0.0000789" izz="0.0002107" />
    </inertial>
    <visual>
      <origin xyz="0 0 0" rpy="0 0 0" />
      <geometry>
        <mesh filename="package://robot_description/meshes/link_4.STL" />
      </geometry>
      <material name="">
        <color rgba="0.827450980392157 0.827450980392157 0.819607843137255 1" />
      </material>
    </visual>
    <collision>
      <origin xyz="0 0 0" rpy="0 0 0" />
      <geometry>
        <mesh filename="package://robot_description/meshes/link_4.STL" />
      </geometry>
    </collision>
  </link>
  <joint name="joint_4" type="revolute">
    <origin xyz="-0.00071398 0.071768 -0.00087296" rpy="1.5708 0 1.5708" />
    <parent link="link_3" />
    <child link="link_4" />
    <axis xyz="0 0 1" />
    <limit lower="-3" upper="3" effort="7" velocity="3" />
  </joint>
  <link name="link_5">
    <inertial>
      <origin xyz="-0.0000294 -0.0433495 -0.0048578" rpy="0 0 0" />
      <mass value="0.4734144" />
      <inertia ixx="0.0004422" ixy="0.0000000" ixz="0.0000001" iyy="0.0002457" iyz="0.0001061" izz="0.0004156" />
    </inertial>
    <visual>
      <origin xyz="0 0 0" rpy="0 0 0" />
      <geometry>
        <mesh filename="package://robot_description/meshes/link_5.STL" />
      </geometry>
      <material name="">
        <color rgba="0.827450980392157 0.827450980392157 0.819607843137255 1" />
      </material>
    </visual>
    <collision>
      <origin xyz="0 0 0" rpy="0 0 0" />
      <geometry>
        <mesh filename="package://robot_description/meshes/link_5.STL" />
      </geometry>
    </collision>
  </link>
  <joint name="joint_5" type="revolute">
    <origin xyz="0.00023228 -0.0022353 0.20325" rpy="-1.5708 0 0" />
    <parent link="link_4" />
    <child link="link_5" />
    <axis xyz="0 0 -1" />
    <limit lower="-3" upper="3" effort="7" velocity="3" />
  </joint>
  <link name="link_6">
    <inertial>
      <origin xyz="0.000232281977285045 -6.28905157118442E-11 0.017419494184961" rpy="0 0 0" />
      <mass value="0.0102510168286635" />
      <inertia ixx="8.9340237298249E-07" ixy="-1.1511058328978E-22" ixz="2.30025241635429E-20" iyy="8.9340237298249E-07" iyz="2.06828787998769E-20" izz="1.58125115444697E-06" />
    </inertial>
    <visual>
      <origin xyz="0 0 0" rpy="0 0 0" />
      <geometry>
        <mesh filename="package://robot_description/meshes/link_6.STL" />
      </geometry>
      <material name="">
        <color rgba="0.827450980392157 0.827450980392157 0.819607843137255 1" />
      </material>
    </visual>
    <collision>
      <origin xyz="0 0 0" rpy="0 0 0" />
      <geometry>
        <mesh filename="package://robot_description/meshes/link_6.STL" />
      </geometry>
    </collision>
  </link>
  <joint name="joint_6" type="revolute">
    <origin xyz="-0.00023228 -0.061253 0.0014853" rpy="1.5708 0 0" />
    <parent link="link_5" />
    <child link="link_6" />
    <axis xyz="0 0 1" />
    <limit lower="-3" upper="3" effort="7" velocity="3" />
  </joint>
</robot>

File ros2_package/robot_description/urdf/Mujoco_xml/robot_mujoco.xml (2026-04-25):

<mujoco model="robot_1">

  <include file="scene.xml"/>
  <compiler angle="radian" meshdir="../../meshes/"/>

  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

  <worldbody>
    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
    <body name="link_1" pos="0.00019927 -0.001877 0.10675">
      <inertial pos="-0.0001798 -0.0062513 -0.0147465" quat="0.995519 0.0944818 0.00032831 0.003958" mass="0.68958" diaginertia="0.000522302 0.000501989 0.000355309"/>
      <joint name="joint_1" pos="0 0 0" axis="0 0 1" range="-3 3" actuatorfrcrange="-27 27"/>
      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
      <body name="link_2" quat="0.707105 -0.707108 0 0">
        <inertial pos="-0.130904 0 0.0144901" quat="0 0.661662 0 0.749802" mass="0.637029" diaginertia="0.00350037 0.0034922 0.000259135"/>
        <joint name="joint_2" pos="0 0 0" axis="0 0 1" range="-3 3" actuatorfrcrange="-27 27"/>
        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
        <body name="link_3" pos="-0.18 0 0" quat="-3.67321e-06 -1 0 0">
          <inertial pos="-0.0058307 0.0495532 0.0062562" quat="0.734745 0.543882 -0.1794 0.363536" mass="0.702419" diaginertia="0.000915743 0.00089766 0.000333097"/>
          <joint name="joint_3" pos="0 0 0" axis="0 0 1" range="-3 3" actuatorfrcrange="-27 27"/>
          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
          <body name="link_4" pos="-0.00071398 0.071768 -0.00087296" quat="0.499998 0.5 0.500002 0.5">
            <inertial pos="0.0002323 0.0070423 0.160009" quat="0.999869 0.0161554 0 0" mass="0.52115" diaginertia="0.002666 0.00265165 0.00020815"/>
            <joint name="joint_4" pos="0 0 0" axis="0 0 1" range="-3 3" actuatorfrcrange="-7 7"/>
            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
            <body name="link_5" pos="0.00023228 -0.0022353 0.20325" quat="0.707105 -0.707108 0 0">
              <inertial pos="-2.94e-05 -0.0433495 -0.0048578" quat="0.59968 0.377138 -0.37585 0.597401" mass="0.473414" diaginertia="0.000466568 0.0004422 0.000194732"/>
              <joint name="joint_5" pos="0 0 0" axis="0 0 -1" range="-3 3" actuatorfrcrange="-7 7"/>
              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
              <body name="link_6" pos="-0.00023228 -0.061253 0.0014853" quat="0.707105 0.707108 0 0">
                <inertial pos="0.000232282 -6.28905e-11 0.0174195" quat="0.5 0.5 -0.5 0.5" mass="0.010251" diaginertia="1.58125e-06 8.93402e-07 8.93402e-07"/>
                <joint name="joint_6" pos="0 0 0" axis="0 0 1" range="-3 3" actuatorfrcrange="-7 7"/>
                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
              </body>
            </body>
          </body>
        </body>
      </body>
    </body>
  </worldbody>


    <default>
     <joint frictionloss="0.2" damping="0.02"/>
     
  </default>
  
  <actuator>

    <motor name= "trq_ctrl_1" joint="joint_1" ctrllimited="true" ctrlrange="-30 30"/>
    <motor name= "trq_ctrl_2" joint="joint_2" ctrllimited="true" ctrlrange="-30 30"/>
    <motor name= "trq_ctrl_3" joint="joint_3" ctrllimited="true" ctrlrange="-30 30"/>
    <motor name= "trq_ctrl_4" joint="joint_4" ctrllimited="true" ctrlrange="-30 30"/>
    <motor name= "trq_ctrl_5" joint="joint_5" ctrllimited="true" ctrlrange="-7 7"/>
    <motor name= "trq_ctrl_6" joint="joint_6" ctrllimited="true" ctrlrange="-7 7"/>

    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

  </actuator>
  
  <sensor>
    <jointpos name="joint_pos_1" joint="joint_1"/>
    <jointpos name="joint_pos_2" joint="joint_2"/>
    <jointpos name="joint_pos_3" joint="joint_3"/>
    <jointpos name="joint_pos_4" joint="joint_4"/>
    <jointpos name="joint_pos_5" joint="joint_5"/>
    <jointpos name="joint_pos_6" joint="joint_6"/>

    <jointvel name="joint_vel_1" joint="joint_1"/>
    <jointvel name="joint_vel_2" joint="joint_2"/>
    <jointvel name="joint_vel_3" joint="joint_3"/>
    <jointvel name="joint_vel_4" joint="joint_4"/>
    <jointvel name="joint_vel_5" joint="joint_5"/>
    <jointvel name="joint_vel_6" joint="joint_6"/>
  </sensor>

  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
</mujoco>

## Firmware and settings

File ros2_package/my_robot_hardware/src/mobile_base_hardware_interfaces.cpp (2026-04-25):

#include "my_robot_hardware/mobile_base_hardware_interface.hpp"
#include <string>
#include <vector>
#include <cmath>
#include <thread>
#include <chrono>
#include "rclcpp/rclcpp.hpp"

namespace
{
// 电机 CAN ID，与 dm_motor_add 中的 master_id 对应
constexpr uint8_t kMotorIds[mobile_base_hardware::kNumJoints] = {
  0x01, 0x02, 0x03, 0x04, 0x05, 0x06};
}  // namespace

namespace mobile_base_hardware
{
  hardware_interface::CallbackReturn MobileBaseHardwareInterface::on_init(const hardware_interface::HardwareInfo &info)
  {
    if (hardware_interface::SystemInterface::on_init(info) != hardware_interface::CallbackReturn::SUCCESS)
    {
      return hardware_interface::CallbackReturn::ERROR;
    }

    // 从 URDF <param> 读取每个关节的 MIT 增益
    for (int i = 0; i < kNumJoints; i++)
    {
      const auto & params = info_.joints[i].parameters;
      auto kp_it = params.find("kp");
      auto kd_it = params.find("kd");
      if (kp_it == params.end() || kd_it == params.end())
      {
        RCLCPP_ERROR(rclcpp::get_logger("MobileBaseHardwareInterface"),
                     "joint_%d 缺少 kp 或 kd 参数，请检查 ros2_control xacro", i + 1);
        return hardware_interface::CallbackReturn::ERROR;
      }
      kp_[i] = std::stod(kp_it->second);
      kd_[i] = std::stod(kd_it->second);
      RCLCPP_INFO(rclcpp::get_logger("MobileBaseHardwareInterface"),
                  "joint_%d  kp=%.1f  kd=%.1f", i + 1, kp_[i], kd_[i]);
    }

    handle = damiao_handle_create(DEV_USB2CANFD_DUAL);

    int device_cnt = damiao_handle_find_devices(handle);
    if (device_cnt == 0)
    {
      RCLCPP_WARN(rclcpp::get_logger("MobileBaseHardwareInterface"), "no device found!");
      damiao_handle_destroy(handle);
      return hardware_interface::CallbackReturn::ERROR;
    }
    return hardware_interface::CallbackReturn::SUCCESS;
  }
  hardware_interface::CallbackReturn MobileBaseHardwareInterface::on_configure(const rclcpp_lifecycle::State &previous_state)
  {
    (void)previous_state;
    int handle_cnt = 0;
    damiao_handle_get_devices(handle, dev_list, &handle_cnt);

    if (device_open(dev_list[0]))
    {
      RCLCPP_INFO(rclcpp::get_logger("MobileBaseHardwareInterface"), "device opened!");
    }
    else
    {
      RCLCPP_ERROR(rclcpp::get_logger("MobileBaseHardwareInterface"), "device open failed!");
      damiao_handle_destroy(handle);
      return hardware_interface::CallbackReturn::ERROR;
    }
    char strBuf[255] = {0};
    device_get_version(dev_list[0], strBuf, sizeof(strBuf));
    RCLCPP_INFO(rclcpp::get_logger("MobileBaseHardwareInterface"), "device version:%s", strBuf);
    device_get_serial_number(dev_list[0], strBuf, sizeof(strBuf));
    RCLCPP_INFO(rclcpp::get_logger("MobileBaseHardwareInterface"), "device sn:%s", strBuf);
    return hardware_interface::CallbackReturn::SUCCESS;
  }
  hardware_interface::CallbackReturn MobileBaseHardwareInterface::on_activate(const rclcpp_lifecycle::State &previous_state)
  {
    (void)previous_state;
    uint32_t nom_baud = 1000000;
    uint32_t dat_baud = 5000000;

    /* 初始化通道波特率 */
    dm_init_channel(dev_list[0], 0, true, nom_baud, dat_baud, 0.75f, 0.75f);

    /* 添加电机 */
    dm_motor_add(DM_4340, 0x01, 0x11);
    dm_motor_add(DM_4340, 0x02, 0x12);
    dm_motor_add(DM_4340, 0x03, 0x13);
    dm_motor_add(DM_4310, 0x04, 0x14);
    dm_motor_add(DM_4310, 0x05, 0x15);
    dm_motor_add(DM_4310, 0x06, 0x16);
    /* 开启通道 */
    device_open_channel(dev_list[0], 0);
    /* 注册回调 */
    device_hook_to_rec(dev_list[0], dm_receive_callback);

    dm_control_enable(dev_list[0]);

    // 等待电机CAN回调至少收到一帧有效反馈，避免 state_q 为0时初始化 command
    // 最多等待500ms，每10ms轮询一次
    bool got_feedback = false;
    for (int retry = 0; retry < 50; retry++)
    {
      std::this_thread::sleep_for(std::chrono::milliseconds(10));
      // 只要任意一轴 state_q 非零就认为收到了反馈
      for (int i = 0; i < kNumJoints; i++)
      {
        double q, dq, tau;
        dm_motor_snapshot(i, &q, &dq, &tau);
        if (std::abs(q) > 1e-6)
        {
          got_feedback = true;
          break;
        }
      }
      if (got_feedback) break;
    }

    if (!got_feedback)
    {
      RCLCPP_WARN(rclcpp::get_logger("MobileBaseHardwareInterface"),
                  "未在500ms内收到电机反馈，初始命令可能为0，请确认电机已上电！");
    }
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

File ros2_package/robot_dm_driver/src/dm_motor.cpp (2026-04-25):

#include "robot_dm_driver/dm_motor.hpp"
#include <mutex>

/* 全局电机表 */
dm_motor_t g_motors[DM_MAX_MOTORS];
int g_motor_count = 0;

/* 保护 g_motors[*].state_q/dq/tau 的互斥锁，
   由 dm_receive_callback（CAN驱动线程）写，
   由 dm_motor_snapshot（ros2_control 控制循环线程）读 */
static std::mutex g_motors_state_mutex;

/* 内部保存设备句柄，供 dm_control_disable 使用 */
static device_handle *g_dev = NULL;

/* 各型号电机限制参数 */
static const dm_limit_param_t g_limit_params[DM_MOTOR_TYPE_COUNT] = {
    {12.566f,  50.0f,  5.0f},   /* DM3507 */
    {3.14159f, 45.0f, 54.0f},   /* DM4310 */
    {3.14159f, 45.0f, 54.0f},   /* DM4340 */
}; 

static uint16_t float_to_uint(float x, float xmin, float xmax, uint8_t bits)
{
    float span = xmax - xmin;
    float data_norm = (x - xmin) / span;
    uint16_t data_uint = (uint16_t)(data_norm * ((1 << bits) - 1));
    return data_uint;
}

static float uint_to_float(uint16_t x, float xmin, float xmax, uint8_t bits)
{
    float span = xmax - xmin;
    float data_norm = (float)x / ((1 << bits) - 1);
    return data_norm * span + xmin;
}

int dm_motor_add(dm_motor_type_t type, uint16_t can_id, uint16_t master_id)
{
    if (g_motor_count >= DM_MAX_MOTORS) {
        printf("[Error] motor table full\n");
        return -1;
    }
    dm_motor_t *m = &g_motors[g_motor_count];
    memset(m, 0, sizeof(dm_motor_t));
    m->can_id = can_id;
    m->master_id = master_id;
    m->motor_type = type;
    m->limit = g_limit_params[type];
    m->active = 1;
    g_motor_count++;
    printf("[Info] motor added: can_id=0x%02X master_id=0x%02X\n", can_id, master_id);
    return 0;
}

dm_motor_t* dm_motor_find(uint16_t id)
{
    for (int i = 0; i < g_motor_count; i++) {
        if (g_motors[i].active &&
            (g_motors[i].can_id == id || g_motors[i].master_id == id)) {
            return &g_motors[i];
        } 
    }
    return NULL;
}

void dm_init_channel(device_handle *dev, uint8_t channel, bool canfd,
                     int bitrate, int dbitrate, float can_sp, float canfd_sp)
{
    g_dev = dev;
    device_channel_set_baud_with_sp(dev, channel, canfd, bitrate, dbitrate, can_sp, canfd_sp);
    printf("**********DM Motor channel init successful**********\n");
}

void dm_control_enable(device_handle *dev)
{
    g_dev = dev;
    uint8_t payload[8] = {0xFF, 0xFF, 0xFF, 0xFF, 0xFF, 0xFF, 0xFF, 0xFC};
    for (int i = 0; i < g_motor_count; i++) {
        if (g_motors[i].active) {
            device_channel_send_fast(dev, 0, g_motors[i].can_id, 1,
                                     false, true, true, 8, payload);
        }
    }
    printf("[Info] all motors enabled\n");
}

void dm_control_disable()
{
    if (g_dev == NULL) {
        printf("[Error] dm_control_disable: device not initialized\n");
        return;
    }
    uint8_t payload[8] = {0xFF, 0xFF, 0xFF, 0xFF, 0xFF, 0xFF, 0xFF, 0xFD};
    for (int i = 0; i < g_motor_count; i++) {
        if (g_motors[i].active) {
            device_channel_send_fast(g_dev, 0, g_motors[i].can_id, 1,
                                     false, true, true, 8, payload);
        }
    }
    printf("[Info] all motors disabled\n");
}

void dm_control_mit(device_handle *dev, uint16_t can_id,
                    float kp, float kd, float q, float dq, float tau)
{
    dm_motor_t *m = dm_motor_find(can_id);
    if (m == NULL) {
        printf("[Error] dm_control_mit: motor id 0x%02X not found\n", can_id);
        return;
    }

    uint16_t kp_uint  = float_to_uint(kp,  0, 500, 12);
    uint16_t kd_uint  = float_to_uint(kd,  0, 5,   12);
    uint16_t q_uint   = float_to_uint(q,   -m->limit.q_max,   m->limit.q_max,   16);
    uint16_t dq_uint  = float_to_uint(dq,  -m->limit.dq_max,  m->limit.dq_max,  12);
    uint16_t tau_uint = float_to_uint(tau, -m->limit.tau_max, m->limit.tau_max, 12);

    uint8_t data[8];
    data[0] = (q_uint >> 8) & 0xff;
    data[1] = q_uint & 0xff;
    data[2] = dq_uint >> 4;
    data[3] = ((dq_uint & 0xf) << 4) | ((kp_uint >> 8) & 0xf);
    data[4] = kp_uint & 0xff;
    data[5] = kd_uint >> 4;
    data[6] = ((kd_uint & 0xf) << 4) | ((tau_uint >> 8) & 0xf);
    data[7] = tau_uint & 0xff;

    device_channel_send_fast(dev, 0, can_id, 1, false, true, true, sizeof(data), data);
}

void dm_receive_callback(usb_rx_frame_t *frame)
{
    uint16_t canID = (uint16_t)frame->head.can_id;

    dm_motor_t *m = dm_motor_find(canID);
    if (m == NULL) {
        return;
    }

    uint16_t q_uint   = ((uint16_t)frame->payload[1] << 8) | frame->payload[2];
    uint16_t dq_uint  = ((uint16_t)frame->payload[3] << 4) | (frame->payload[4] >> 4);
    uint16_t tau_uint = ((uint16_t)(frame->payload[4] & 0xf) << 8) | frame->payload[5];

    double new_q   = uint_to_float(q_uint,   -m->limit.q_max,   m->limit.q_max,   16);
    double new_dq  = uint_to_float(dq_uint,  -m->limit.dq_max,  m->limit.dq_max,  12);
    double new_tau = uint_to_float(tau_uint, -m->limit.tau_max, m->limit.tau_max, 12);

    {
        std::lock_guard<std::mutex> lock(g_motors_state_mutex);
        m->state_q   = new_q;
        m->state_dq  = new_dq;
        m->state_tau = new_tau;
    }
}

void dm_motor_snapshot(int idx, double *out_q, double *out_dq, double *out_tau)
{
    std::lock_guard<std::mutex> lock(g_motors_state_mutex);
    *out_q   = g_motors[idx].state_q;
    *out_dq  = g_motors[idx].state_dq;
    *out_tau = g_motors[idx].state_tau;
}

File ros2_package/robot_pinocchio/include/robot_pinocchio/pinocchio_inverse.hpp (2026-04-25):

#ifndef PINOCCHIO_INVERSE_HPP
#define PINOCCHIO_INVERSE_HPP
#include <array>
#include <algorithm>
#include <Eigen/Dense>
#include "pinocchio/spatial/explog.hpp"
#include "pinocchio/algorithm/kinematics.hpp"
#include "pinocchio/algorithm/jacobian.hpp"
#include "pinocchio/algorithm/joint-configuration.hpp"
#include "pinocchio/parsers/urdf.hpp"
#include <pinocchio/algorithm/rnea.hpp>
enum AxisIndex
{
  LEFTX = 0,
  LEFTY = 1,
  LEFT_TRIGGER = 2,
  RIGHTX = 3,
  RIGHTY = 4,
  RIGHT_TRIGGER = 5,
  DPAD_X = 6,
  DPAD_Y = 7
};

enum ButtonIndex
{
  BUTTON_A = 0,
  BUTTON_B = 1,
  BUTTON_X = 2,
  BUTTON_Y = 3,
  BUTTON_LB = 4,
  BUTTON_RB = 5
};

struct JointStateData {
  std::array<double, 6> positions = {};
};

struct JoyData {
  std::array<double, 8> axes   = {};
  std::array<int, 6>    buttons = {};
};

class pinocchio_inverse {
public:
  pinocchio_inverse();
  ~pinocchio_inverse();

  // 每个控制周期调用一次，输入实际关节角和手柄数据，结果写入 qik
  void update(pinocchio::Model &model, pinocchio::Data &data,
              const Eigen::VectorXd &q, const JoyData &joy);
  //输出计算出的关节速度
  Eigen::VectorXd v_;
  // 奇异度指标：<1 接近奇异，>=1 正常
  double ratio = 1.0;
  Eigen::Vector3d last_sync_trans_ = Eigen::Vector3d::Zero();
  double factor = 0.03;               // 速度关节变量 
private:
  static constexpr int    JOINT_ID = 6;
  static constexpr double IK_EPS   = 0.01;  // 奇异点判断阈值
  static constexpr double IK_DT    = 0.04;   // IK 积分步长

  // DLS 逆运动学求解，结果更新至 qik
  void ik_solve(pinocchio::Model &model, pinocchio::Data &data,
                const Eigen::Matrix<double, 6, 1> &v_des,const Eigen::VectorXd &q);

  // 手柄累加状态
  typedef Eigen::Matrix<double, 6, 1> Vector6d;
  Vector6d v_world = Vector6d::Zero();

  // 模式标志
  bool initialized_  = false;
  double v_change_ = 0;
  double v_change_last = 0;
  // IK 中间量（预分配，避免频繁动态内存）
  Eigen::MatrixXd          J_;
  pinocchio::Data::Matrix6 JJt_;
};

#endif // PINOCCHIO_INVERSE_HPP

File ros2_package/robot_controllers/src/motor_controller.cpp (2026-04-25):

#include "robot_controllers/motor_controller.hpp"
#include "pluginlib/class_list_macros.hpp"
#include "rclcpp/logging.hpp"

namespace robot_controller
{

MotorController::MotorController() : controller_interface::ControllerInterface() {}

controller_interface::CallbackReturn MotorController::on_init()
{
    joint_names_  = auto_declare<std::vector<std::string>>("joints", {}); 
    control_mode_ = auto_declare<std::string>("control_mode", "position_ff");
    auto_declare<std::string>("urdf_path", "");
    return controller_interface::CallbackReturn::SUCCESS; //初始化声明参数
}

controller_interface::CallbackReturn MotorController::on_configure(
    const rclcpp_lifecycle::State & previous_state)
{
    (void)previous_state;
    // 获取配置文件写入的参数
    joint_names_  = get_node()->get_parameter("joints").as_string_array();
    control_mode_ = get_node()->get_parameter("control_mode").as_string(); 

    if (joint_names_.empty())
    {
        RCLCPP_ERROR(get_node()->get_logger(), "Parameter 'joints' must not be empty.");
        return controller_interface::CallbackReturn::ERROR;
    }

    if (control_mode_ != "position_ff" && control_mode_ != "gravity_comp")
    {
        RCLCPP_ERROR(get_node()->get_logger(),
            "Unknown control_mode '%s'. Use 'position_ff' or 'gravity_comp'.",
            control_mode_.c_str());
        return controller_interface::CallbackReturn::ERROR;
    }

    if (control_mode_ == "gravity_comp")
    {   //如果是重力补偿控制模式，需要为pinocchio模型获取urdf文件路径
        const std::string urdf_path =
            get_node()->get_parameter("urdf_path").as_string();

        if (urdf_path.empty())
        {
            RCLCPP_ERROR(get_node()->get_logger(),
                "gravity_comp mode requires 'urdf_path' parameter.");
            return controller_interface::CallbackReturn::ERROR;
        }

        try
        {
            pin_model_ = std::make_unique<pinocchio::Model>();
            pinocchio::urdf::buildModel(urdf_path, *pin_model_);
            pin_data_  = std::make_unique<pinocchio::Data>(*pin_model_);
            RCLCPP_INFO(get_node()->get_logger(),
                "Pinocchio model loaded: nq=%d  nv=%d  urdf=%s",
                pin_model_->nq, pin_model_->nv, urdf_path.c_str());
        }
        catch (const std::exception & e)
        {
            RCLCPP_ERROR(get_node()->get_logger(),
                "Failed to build Pinocchio model: %s", e.what());
            return controller_interface::CallbackReturn::ERROR;
        }
    }

    auto callback = [this](const Float64MultiArray::SharedPtr msg) -> void {
        rt_command_buffer_.writeFromNonRT(msg);  
    };

    command_subscriber_ = get_node()->create_subscription<Float64MultiArray>(
        "arm_MIT_command_controller/commands", rclcpp::SystemDefaultsQoS(), callback); //定义订阅者，接收上游节点数据

    RCLCPP_INFO(get_node()->get_logger(),
        "MotorController configured: %zu joints, mode='%s'.",
        joint_names_.size(), control_mode_.c_str());

    return controller_interface::CallbackReturn::SUCCESS;
}

controller_interface::InterfaceConfiguration
MotorController::command_interface_configuration() const //配置命令接口
{
    controller_interface::InterfaceConfiguration config;
    config.type = controller_interface::interface_configuration_type::INDIVIDUAL;

    for (const auto & joint_name : joint_names_)
    {
        config.names.push_back(joint_name + "/position");
        config.names.push_back(joint_name + "/velocity");
        config.names.push_back(joint_name + "/effort");
    }
    return config;
}

controller_interface::InterfaceConfiguration
MotorController::state_interface_configuration() const //配置状态接口
{
    controller_interface::InterfaceConfiguration config;
    config.type = controller_interface::interface_configuration_type::INDIVIDUAL;

    for (const auto & joint_name : joint_names_)
    {
        config.names.push_back(joint_name + "/position");
        config.names.push_back(joint_name + "/velocity");
        config.names.push_back(joint_name + "/effort");
    }
    return config;
}

controller_interface::CallbackReturn MotorController::on_activate(
    const rclcpp_lifecycle::State & previous_state)
{
    (void)previous_state;

    // Each joint claims 3 command interfaces: position / velocity / effort
    const size_t expected = joint_names_.size() * 3;
    if (command_interfaces_.size() != expected)
    {
        RCLCPP_ERROR(
            get_node()->get_logger(),
            "Expected %zu command interfaces, got %zu.",
            expected, command_interfaces_.size());
        return controller_interface::CallbackReturn::ERROR;
    }
    
    // 初始化 command = current state
    initialized_ = false;
    joint_cmd_pos_.resize(joint_names_.size(), 0.0);
    joint_cmd_last_pos_.resize(joint_names_.size(), 0.0);
    joint_cmd_last_vel_.resize(joint_names_.size(), 0.0);

    for (size_t i = 0; i < joint_names_.size(); ++i)
    {
        double pos = state_interfaces_[i * 3 + 0].get_value(); //获取状态接口数据，状态接口数据接收的是hardware数据
        double vel = state_interfaces_[i * 3 + 1].get_value();
        double eff = 0.f;

        joint_cmd_pos_[i]      = pos;
        joint_cmd_last_pos_[i] = pos;
        joint_cmd_last_vel_[i] = vel;

        command_interfaces_[i * 3 + 0].set_value(pos);  
        command_interfaces_[i * 3 + 1].set_value(vel);
        command_interfaces_[i * 3 + 2].set_value(eff);
    }
    return controller_interface::CallbackReturn::SUCCESS;
}

controller_interface::CallbackReturn MotorController::on_deactivate(
    const rclcpp_lifecycle::State & previous_state)
{
    (void)previous_state;
    return controller_interface::CallbackReturn::SUCCESS;
}
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

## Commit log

2026-04-25 第一次提交
    [12轴垫片.SLDPRT, 12轴连接件.SLDPRT, 12轴连接件.STEP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]
2026-04-26 添加README.md
2026-04-26 修改README.md
2026-04-26 修改README
